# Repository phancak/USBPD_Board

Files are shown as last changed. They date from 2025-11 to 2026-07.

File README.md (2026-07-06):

# ⚡ Modular Power Distribution & USB-PD System

<div align="center">
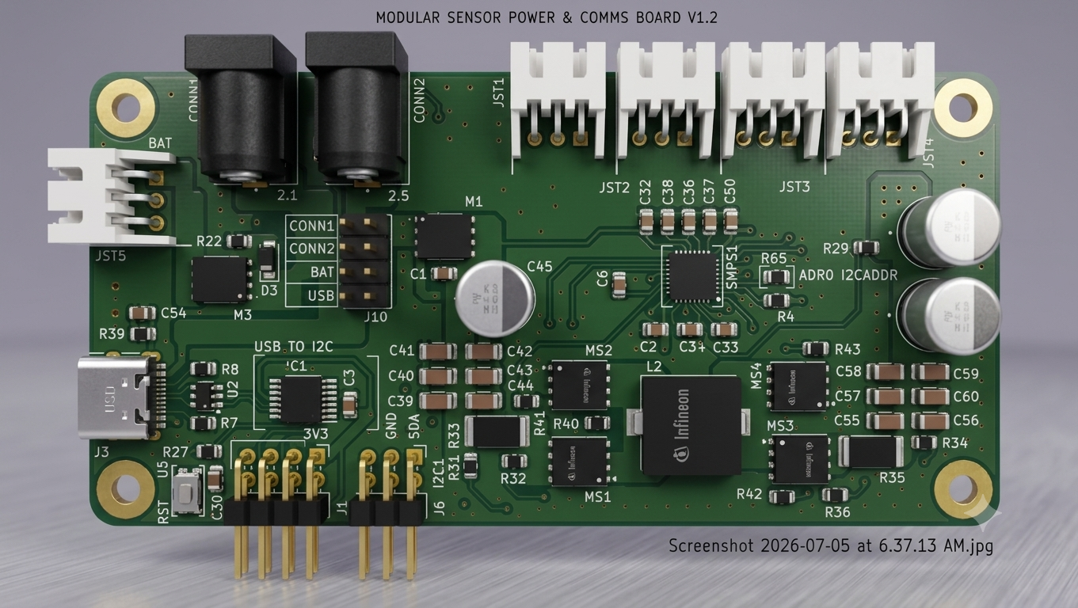
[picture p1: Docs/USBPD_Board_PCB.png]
USBPD PCB 3D Render
  
  <br>
  <em>4-layer PCB diagram.</em>
</div>

### Intelligent Multi-Source Power Management for Mixed-Signal Platforms

## 📑 Quick Access
* [**📂 View Project Schematics (PDF)**](./Schematics/USBPD_Board_Schematics.pdf)

## 📖 Overview
This project is a high-efficiency, multi-input **Power Distribution Board** designed to provide stable, low-noise rails for interchangeable high-performance modules. It serves as the primary power hub for my **24-bit Precision ADC** and **STM32H7S3 System-on-Module** projects.

The system is engineered for maximum field flexibility, allowing a single instrumentation stack to be powered via laboratory bench supplies, USB-C PD sources, or mobile battery packs.

---

## 🛠 Technical Architecture

### 1. Power Entry & Negotiation
The board features a triple-redundant input strategy to support diverse operating environments:
* **USB Power Delivery:** Utilizes an **MCP2221A-I/ST** USB-to-I2C bridge to communicate with PD controllers and negotiate specific voltage profiles.
* **DC Input:** A standard barrel jack for **12V DC** wall converters, ideal for stationary bench-top development.
* **Battery Port:** A dedicated high-current connector for **Lithium-Ion/Polymer battery packs**, enabling untethered mobile data acquisition.

### 2. Digitally Enhanced Conversion
At the core is the **MCP19061-E/RTB**, a Digitally Enhanced Power Analog (DEPA) controller. 
* **Integrated MCU Control:** Combines the performance of an analog peak current mode controller with the flexibility of a microcontroller.
* **Dynamic Regulation:** Enables real-time telemetry and adjustment of output levels to match the requirements of the downstream load.
* **Protection Circuitry:** Hardware-level Under-Voltage Lockout (UVLO), Over-Voltage Protection (OVP), and thermal shutdown.

### 3. Distribution & Filtering
* **4-Way Power Bus:** Features four precision power connectors to distribute clean rails to a stack of interchangeable boards.
* **Noise Mitigation:** Designed with localized LC filtering and optimized PCB return paths to ensure switching noise from the DC-DC stage does not compromise the 120dB SNR performance of connected ADC modules.

---

## 📐 Hardware Specifications

| Feature | Component / Specification |
| :--- | :--- |
| **Main Controller** | Microchip MCP19061 (Integrated MCU + PWM) |
| **USB Interface** | MCP2221A-I/ST (USB-to-I2C/UART Bridge) |
| **Input Range** | Negotiated USB-PD / 12V DC / Battery |
| **Topology** | Synchronous Buck-Boost Converter |
| **Output Ports** | 4x Interconnect Headers |

---

## 🏗 System Integration Philosophy
This board was developed to solve the "Power Bottleneck" in modular hardware design. By decoupling the power stage from the logic and sensing stages, the system achieves:

1.  **High Modularity:** The "Interchangeable Device" architecture allows for swapping analog front-ends or digital processing units without redesigning the power delivery network.
2.  **Field Readiness:** The seamless transition to battery power makes the entire instrumentation stack viable for real-world environmental and oceanographic data collection.
3.  **Stability:** Centralized regulation reduces ground loops and phase coherency issues common in multi-board "nest" wiring.

---

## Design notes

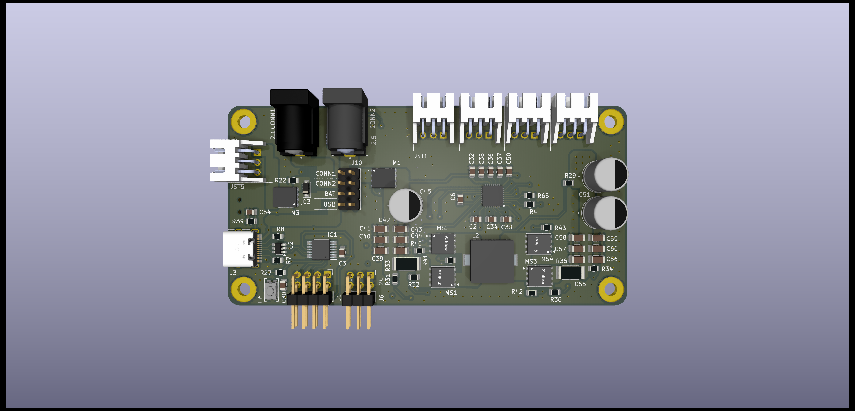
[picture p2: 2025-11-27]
USBPD_Board.png

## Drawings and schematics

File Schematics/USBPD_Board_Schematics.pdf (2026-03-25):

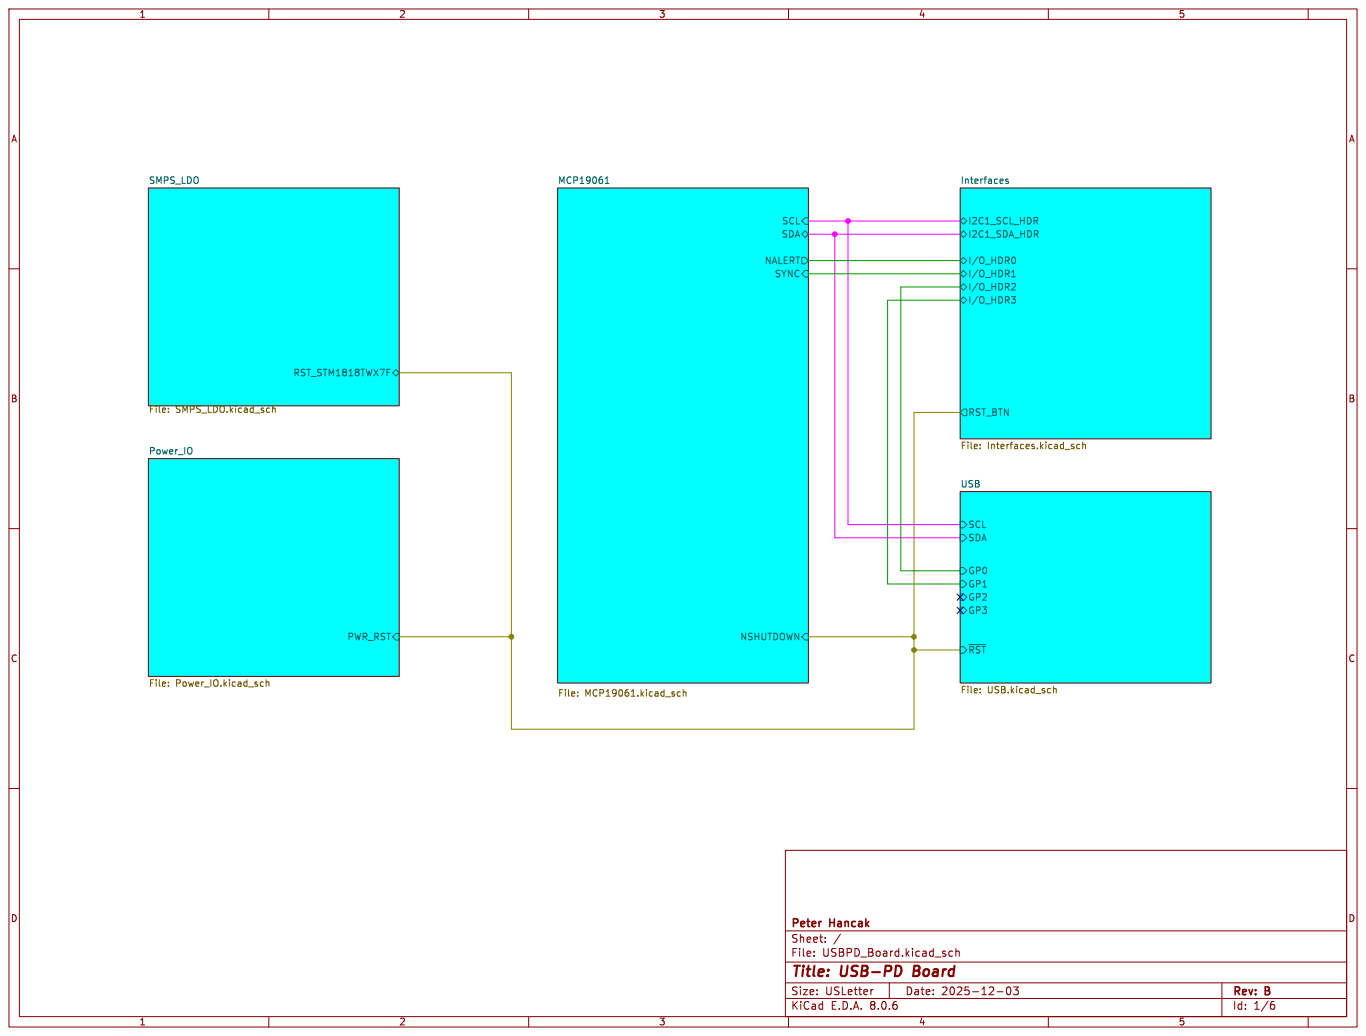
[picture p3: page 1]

Id: 1/6 Title: USB-PD Board

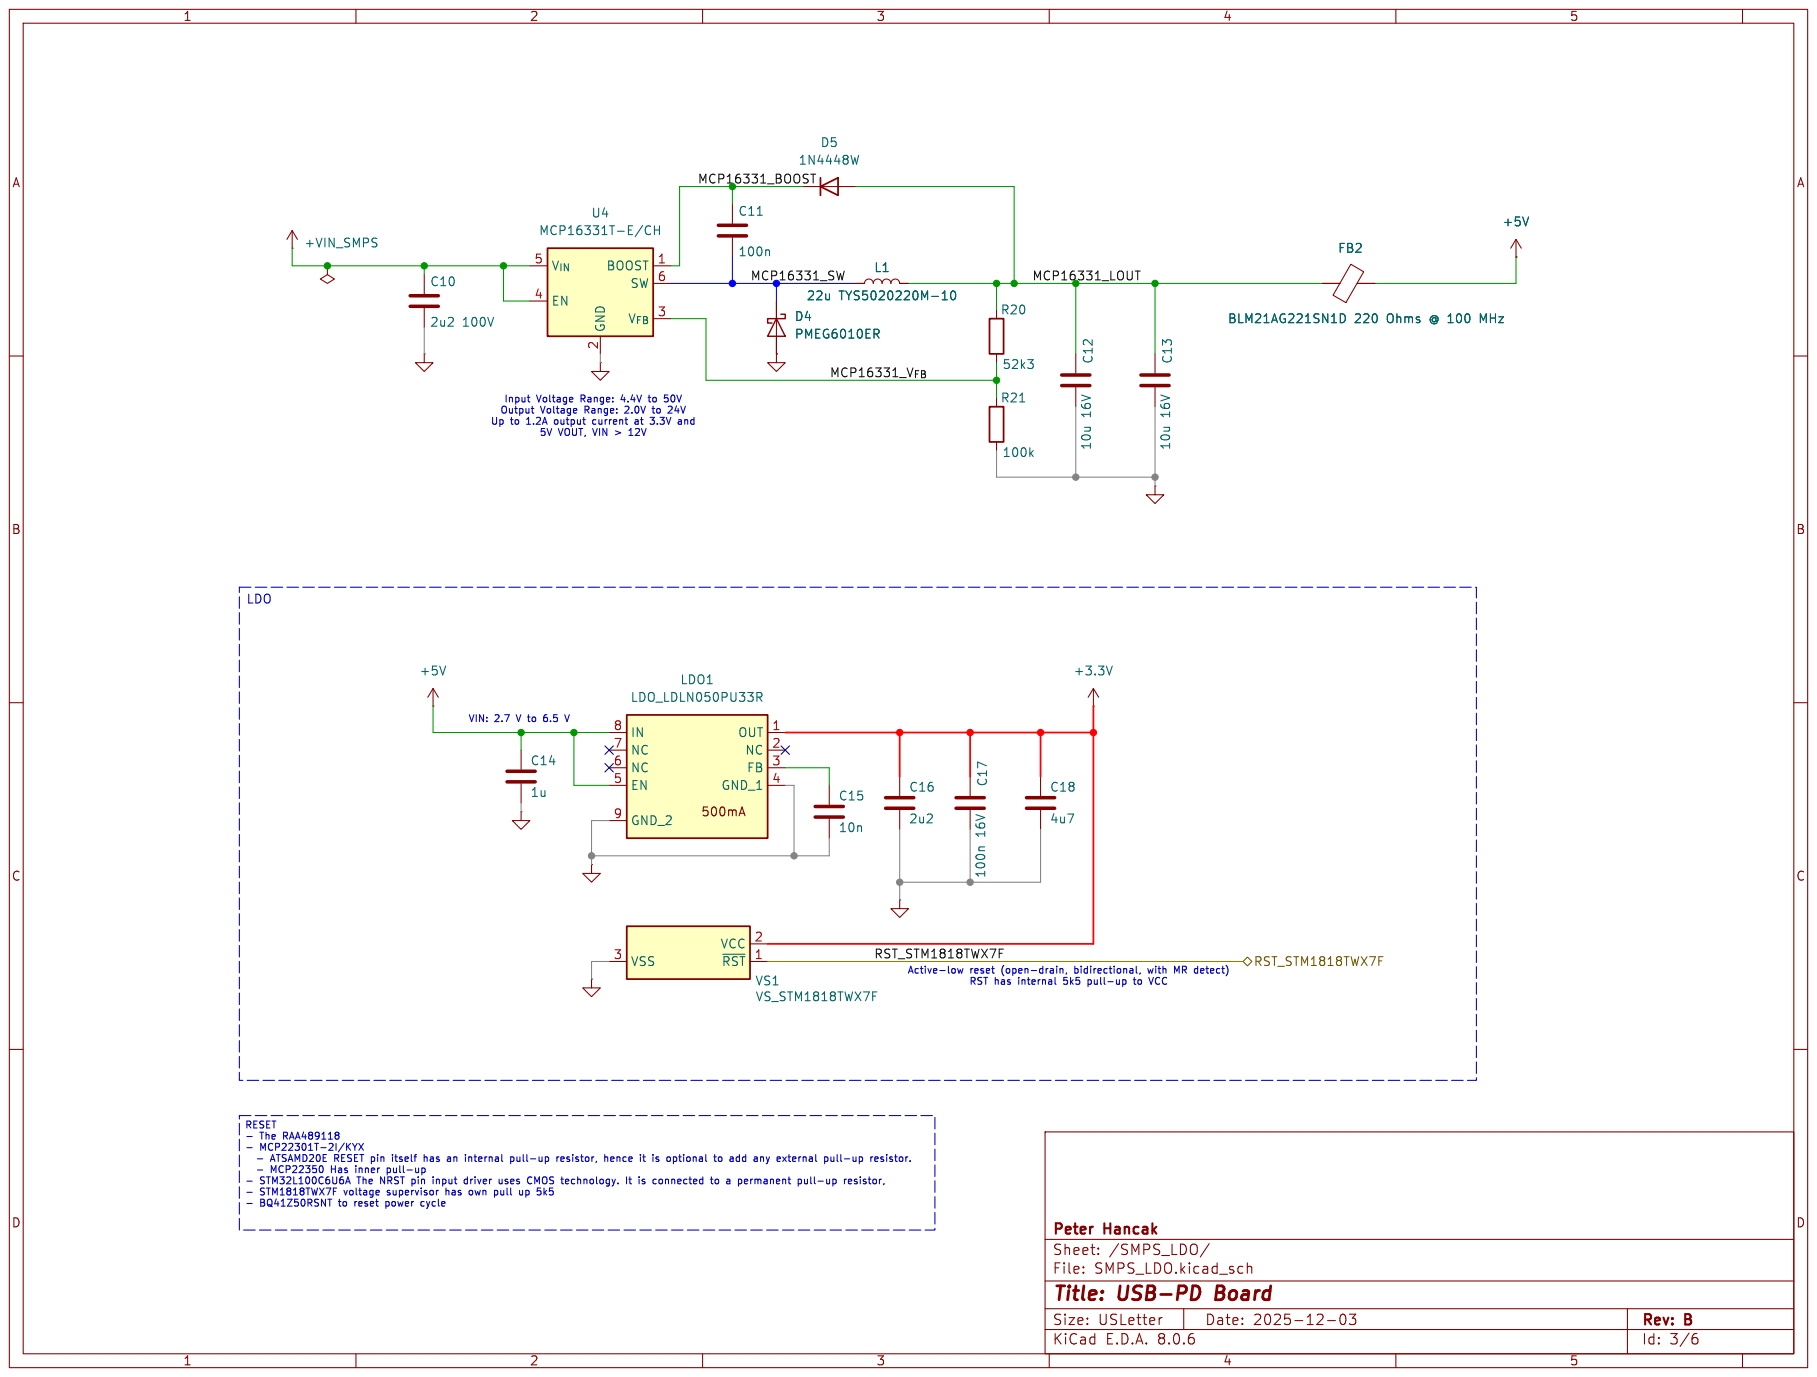
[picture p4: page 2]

2 V_{FB}3 EN 4 V_{IN} 5 SW 6 U4 MCP16331T-E/CH

- BQ41Z50RSNT to reset power cycle

Id: 3/6 Title: USB-PD Board

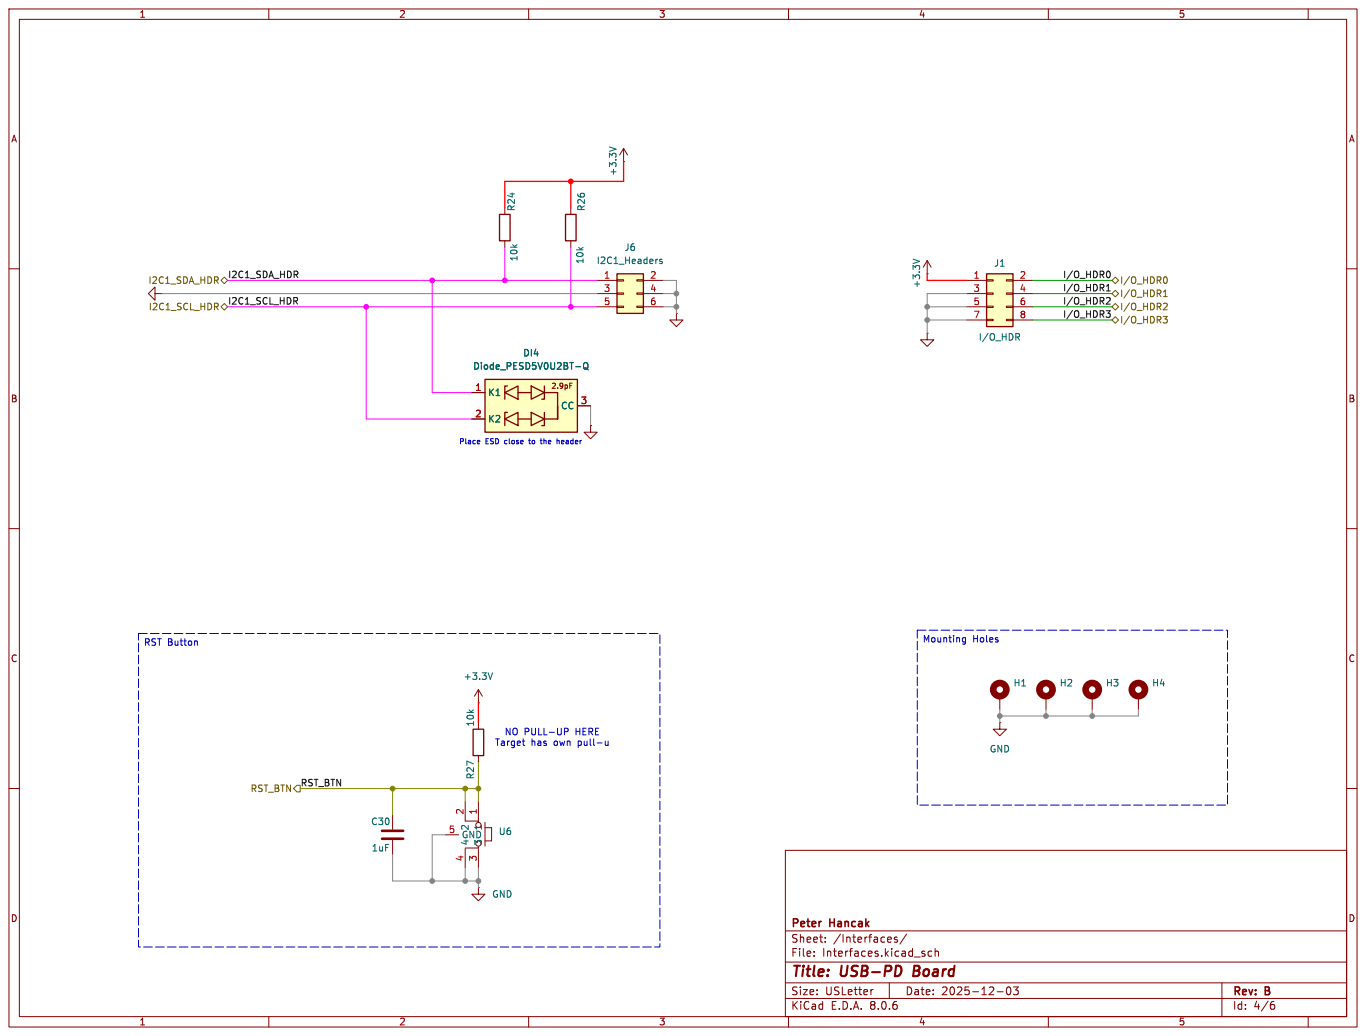
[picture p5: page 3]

Id: 4/6 Title: USB-PD Board

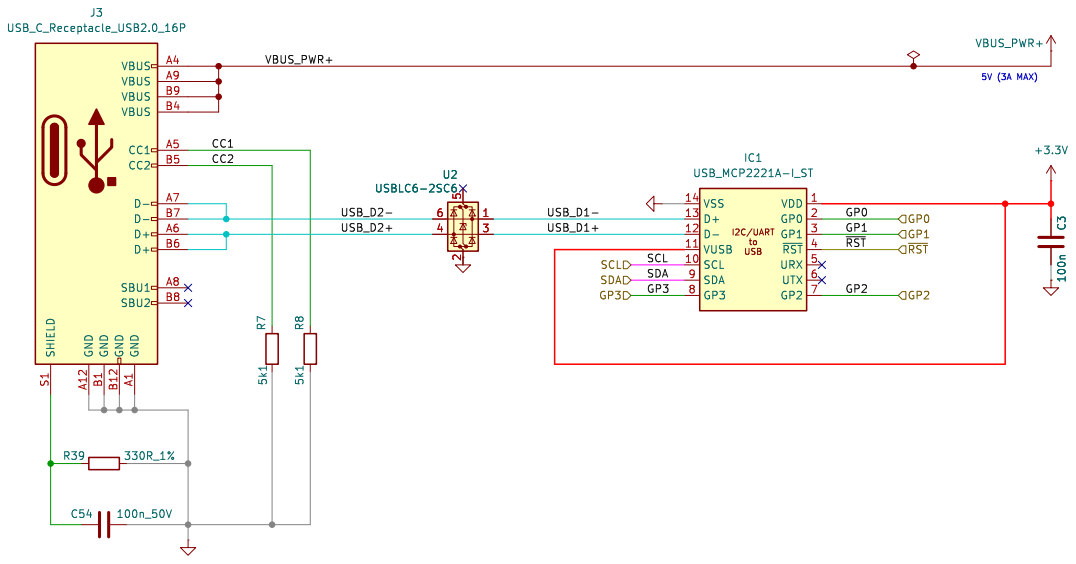
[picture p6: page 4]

Id: 6/6 Title: USB-PD Board

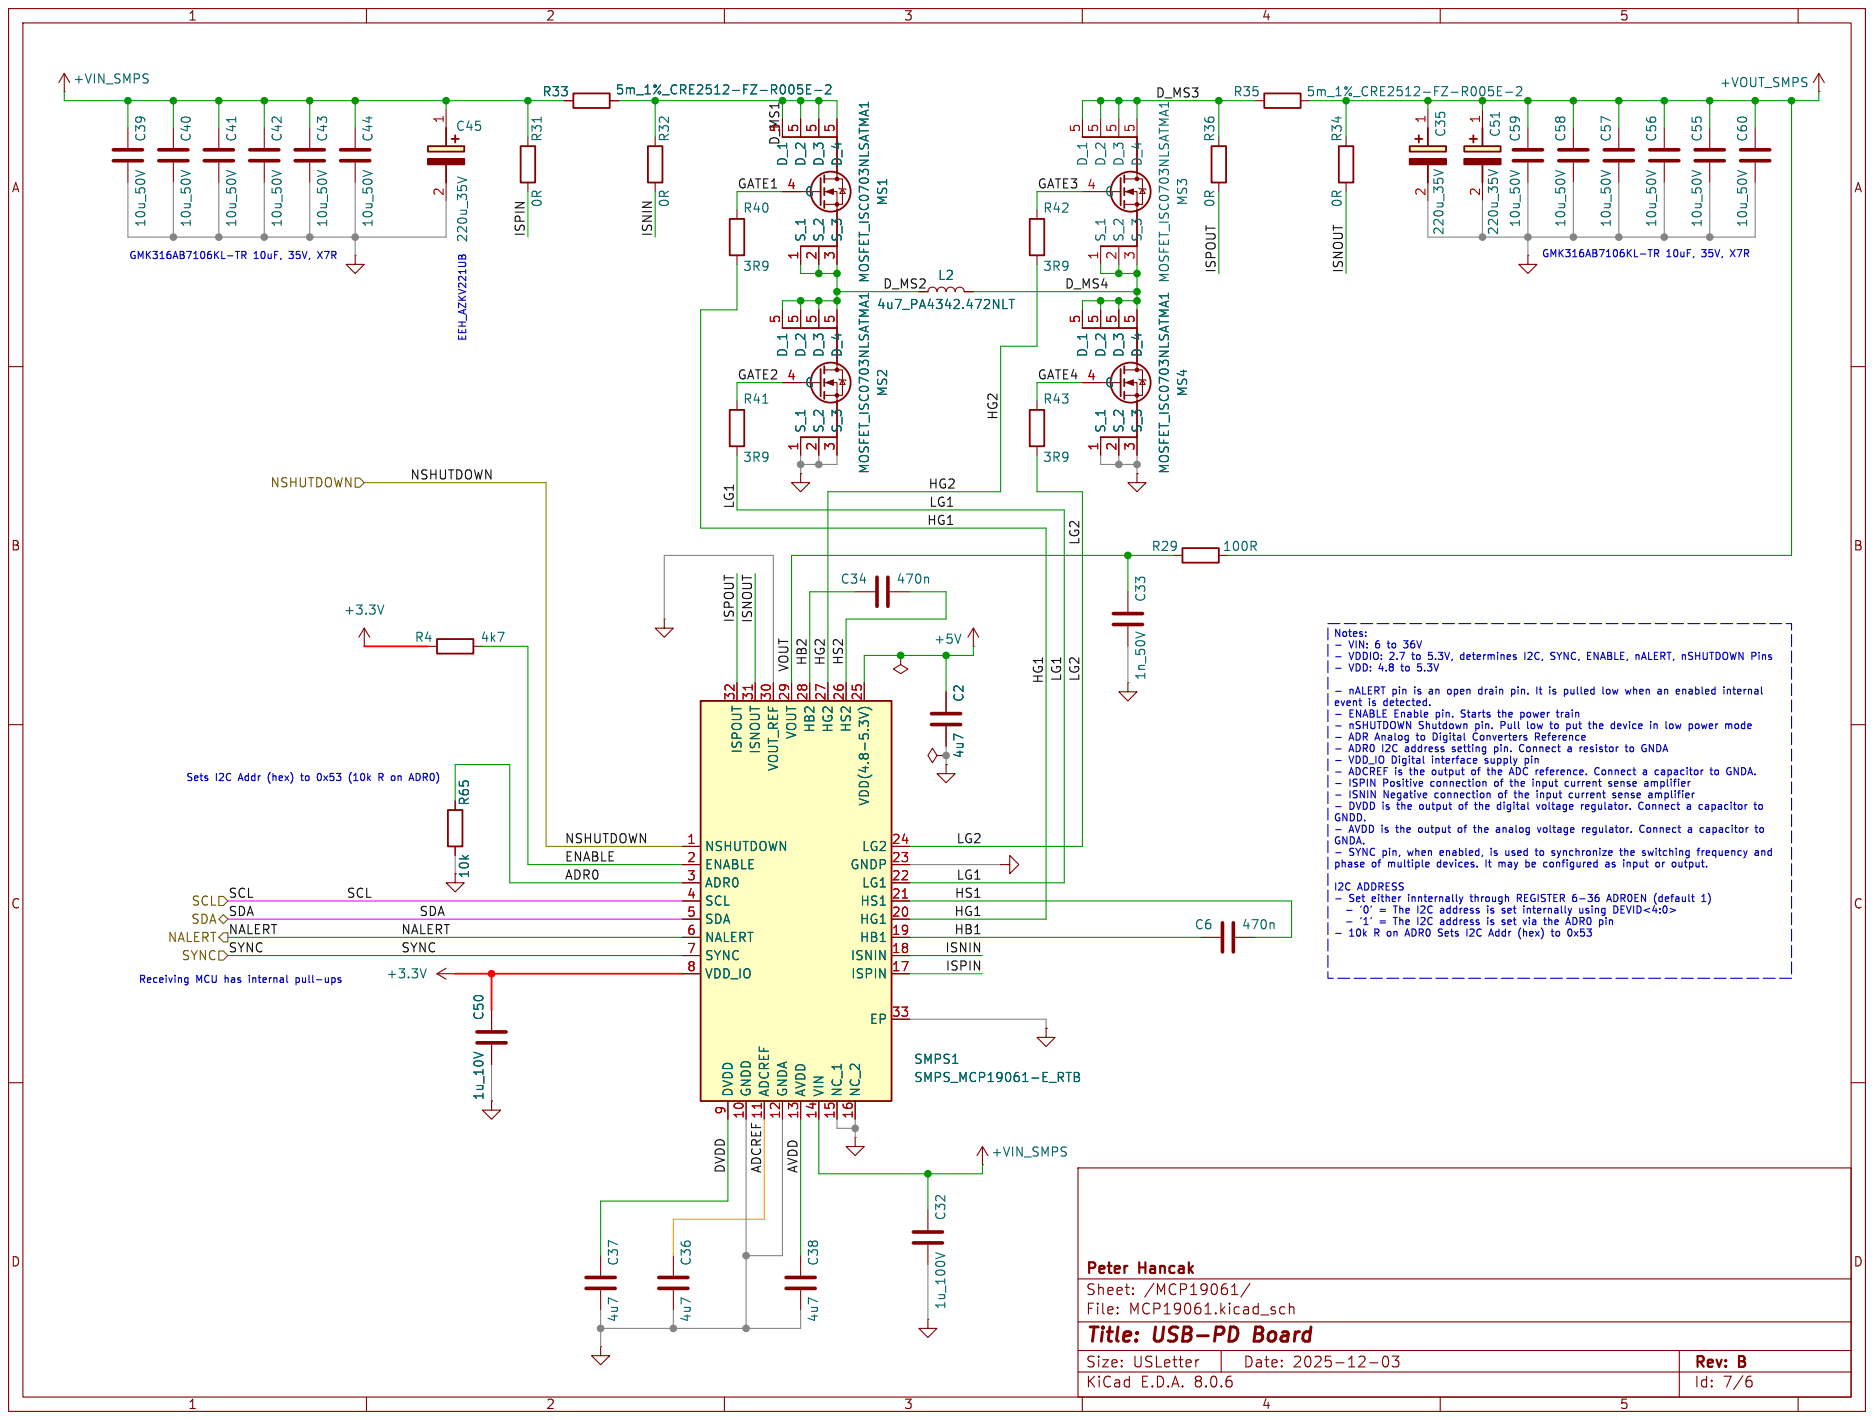
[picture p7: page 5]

- 10k R on ADR0 Sets I2C Addr (hex) to 0x53 C2 4u7

- nALERT pin is an open drain pin. It is pulled low when an enabled internal event is detected. - ENABLE Enable pin. Starts the power train

- nSHUTDOWN Shutdown pin. Pull low to put the device in low power mode

I2C ADDRESS
- '1' = The I2C address is set via the ADR0 pin

Id: 7/6 Title: USB-PD Board

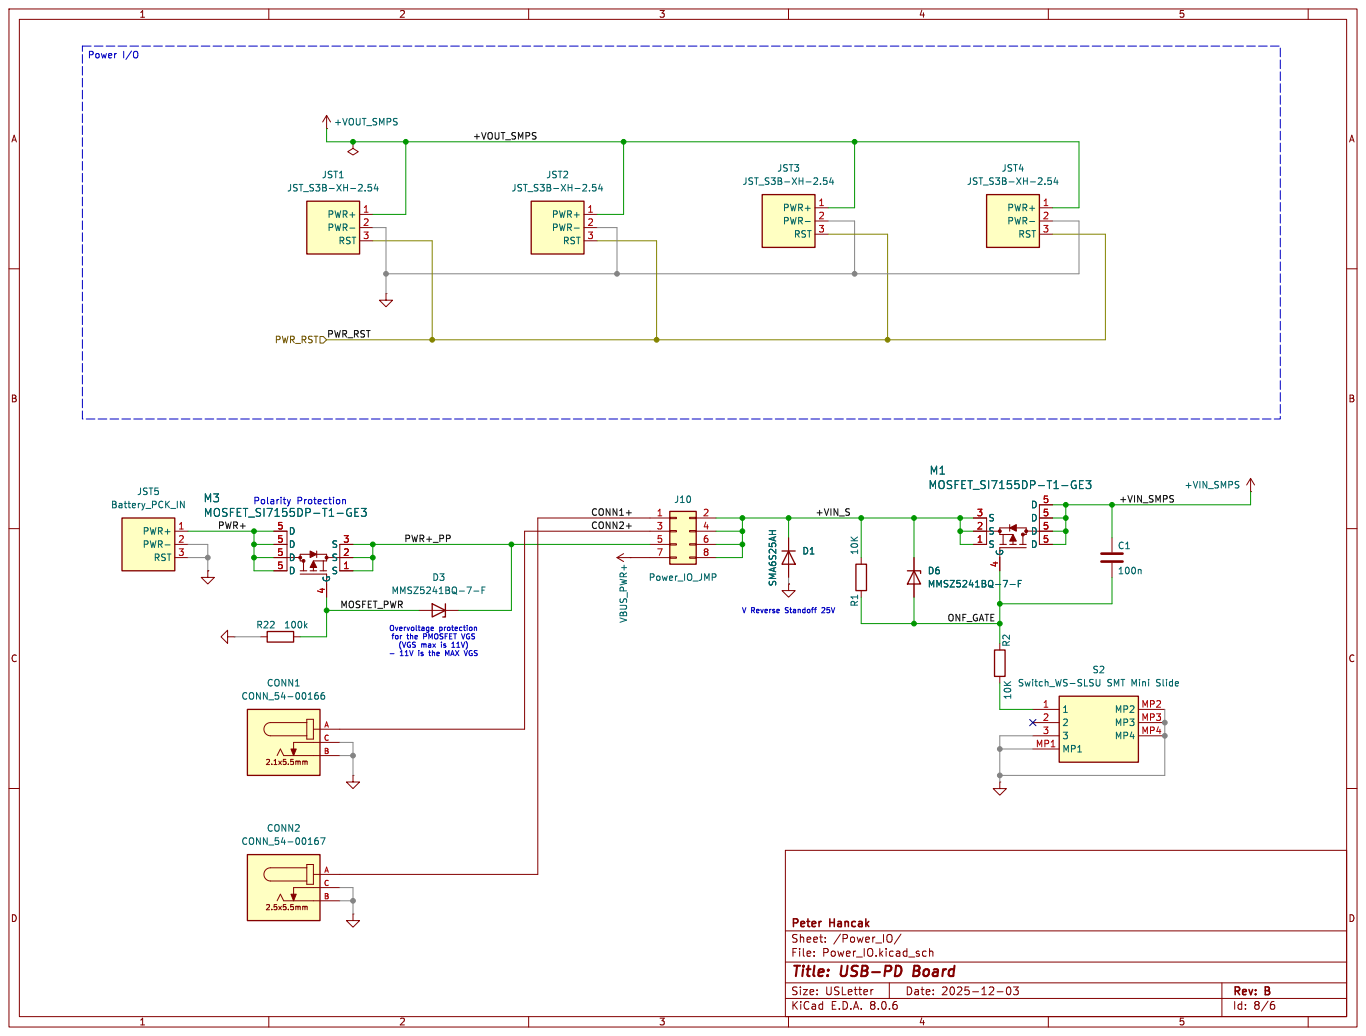
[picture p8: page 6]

for the PMOSFET VGS
(VGS max is 11V)
- 11V is the MAX VGS

Id: 8/6 Title: USB-PD Board

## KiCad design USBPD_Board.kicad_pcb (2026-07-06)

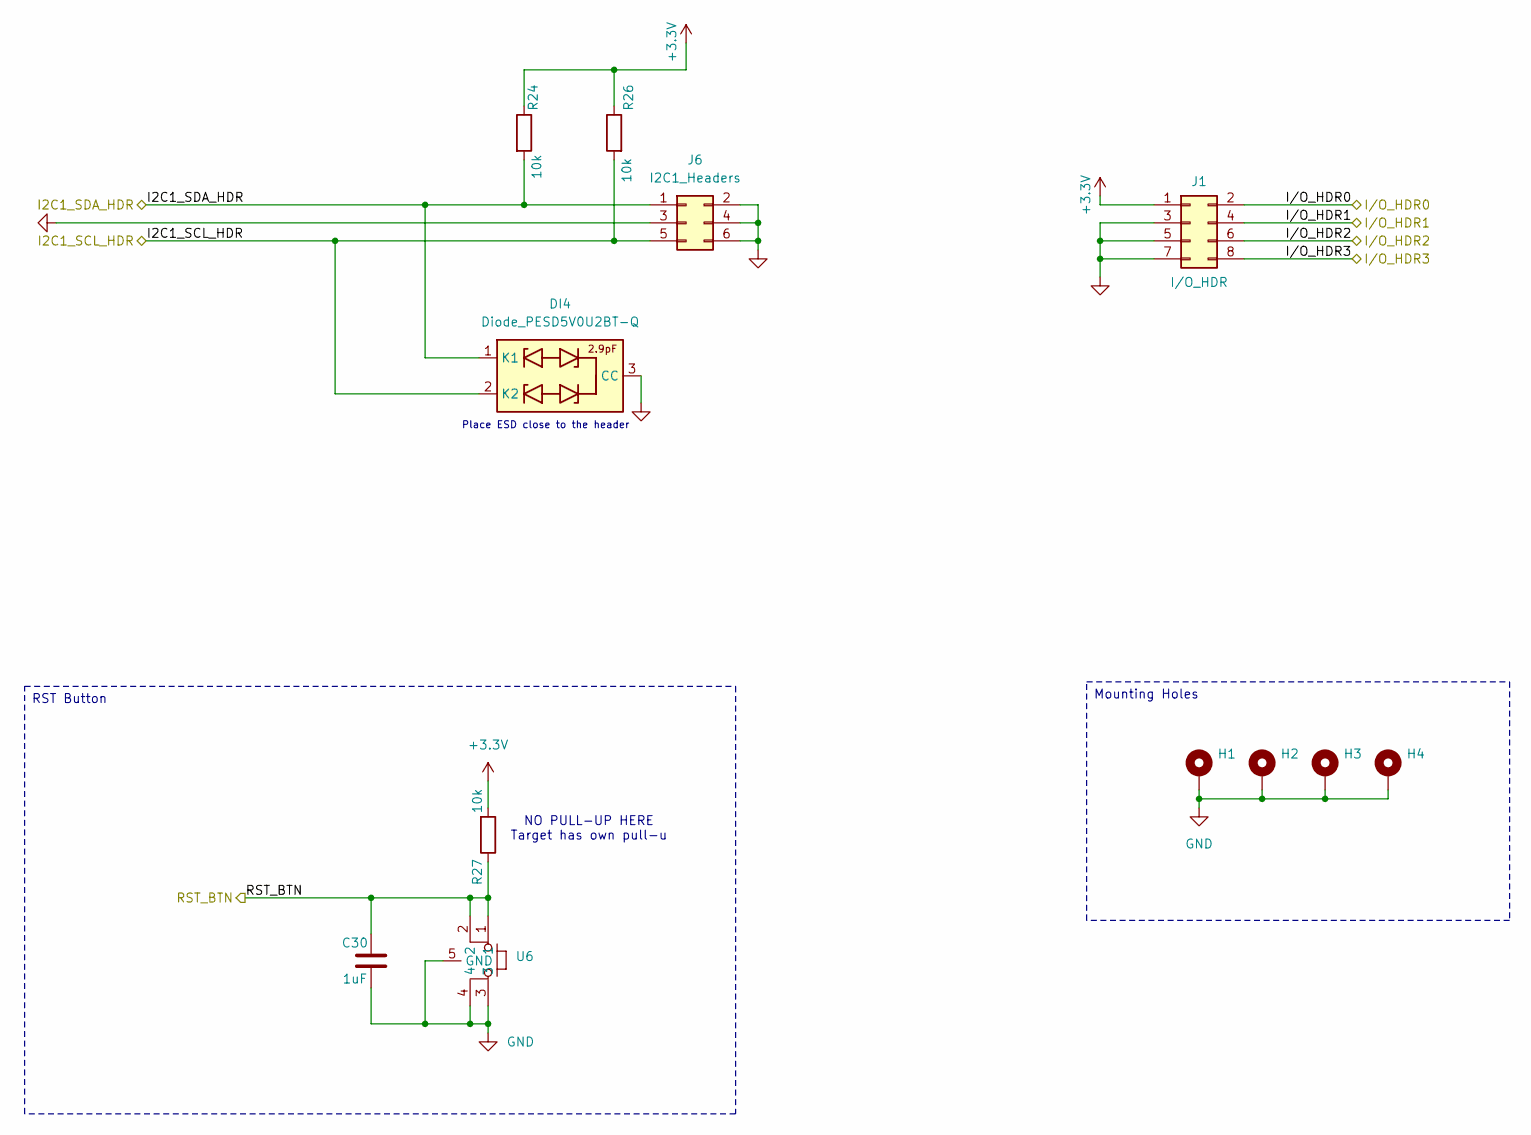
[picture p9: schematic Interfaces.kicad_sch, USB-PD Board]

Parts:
C30: 1uF; C_0805_2012Metric
DI4: Diode_PESD5V0U2BT-Q; SOT-23; Manufacturer_Part_Number BZX84C6V2-7-F; Mouser Part Number 621-BZX84C6V2-F
H1, H2, H3, H4: MountingHole_Pad; MountingHole_3.2mm_M3_Pad
J1: I/O_HDR; PinHeader_2x04_P2.54mm_Horizontal
J6: I2C1_Headers; PinHeader_2x03_P2.54mm_Horizontal
R24, R26, R27: 10k; R_0805_2012Metric
U6: Button_KMR231GLFS

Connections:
+3.3V: J1.1, R24.1, R26.1, R27.2; also elsewhere on the board
/Interfaces/I2C1_SCL_HDR: DI4.2 (K2), J6.5, R26.2; also elsewhere on the board
/Interfaces/I2C1_SDA_HDR: DI4.1 (K1), J6.1, R24.2; also elsewhere on the board
/Interfaces/I/O_HDR0: J1.2; also elsewhere on the board
/Interfaces/I/O_HDR1: J1.4; also elsewhere on the board
/Interfaces/I/O_HDR2: J1.6; also elsewhere on the board
/Interfaces/I/O_HDR3: J1.8; also elsewhere on the board
/Interfaces/RST_BTN: C30.2, R27.1, U6.1, U6.2; also elsewhere on the board
GND: C30.1, DI4.3 (CC), H1.1, H2.1, H3.1, H4.1, J1.3, J1.5, J1.7, J6.2, J6.3, J6.4, J6.6, U6.3, U6.4, U6.5 (GND); also elsewhere on the board

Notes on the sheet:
Place ESD close to the header
NO PULL-UP HERE Target has own pull-u
Mounting Holes
RST Button

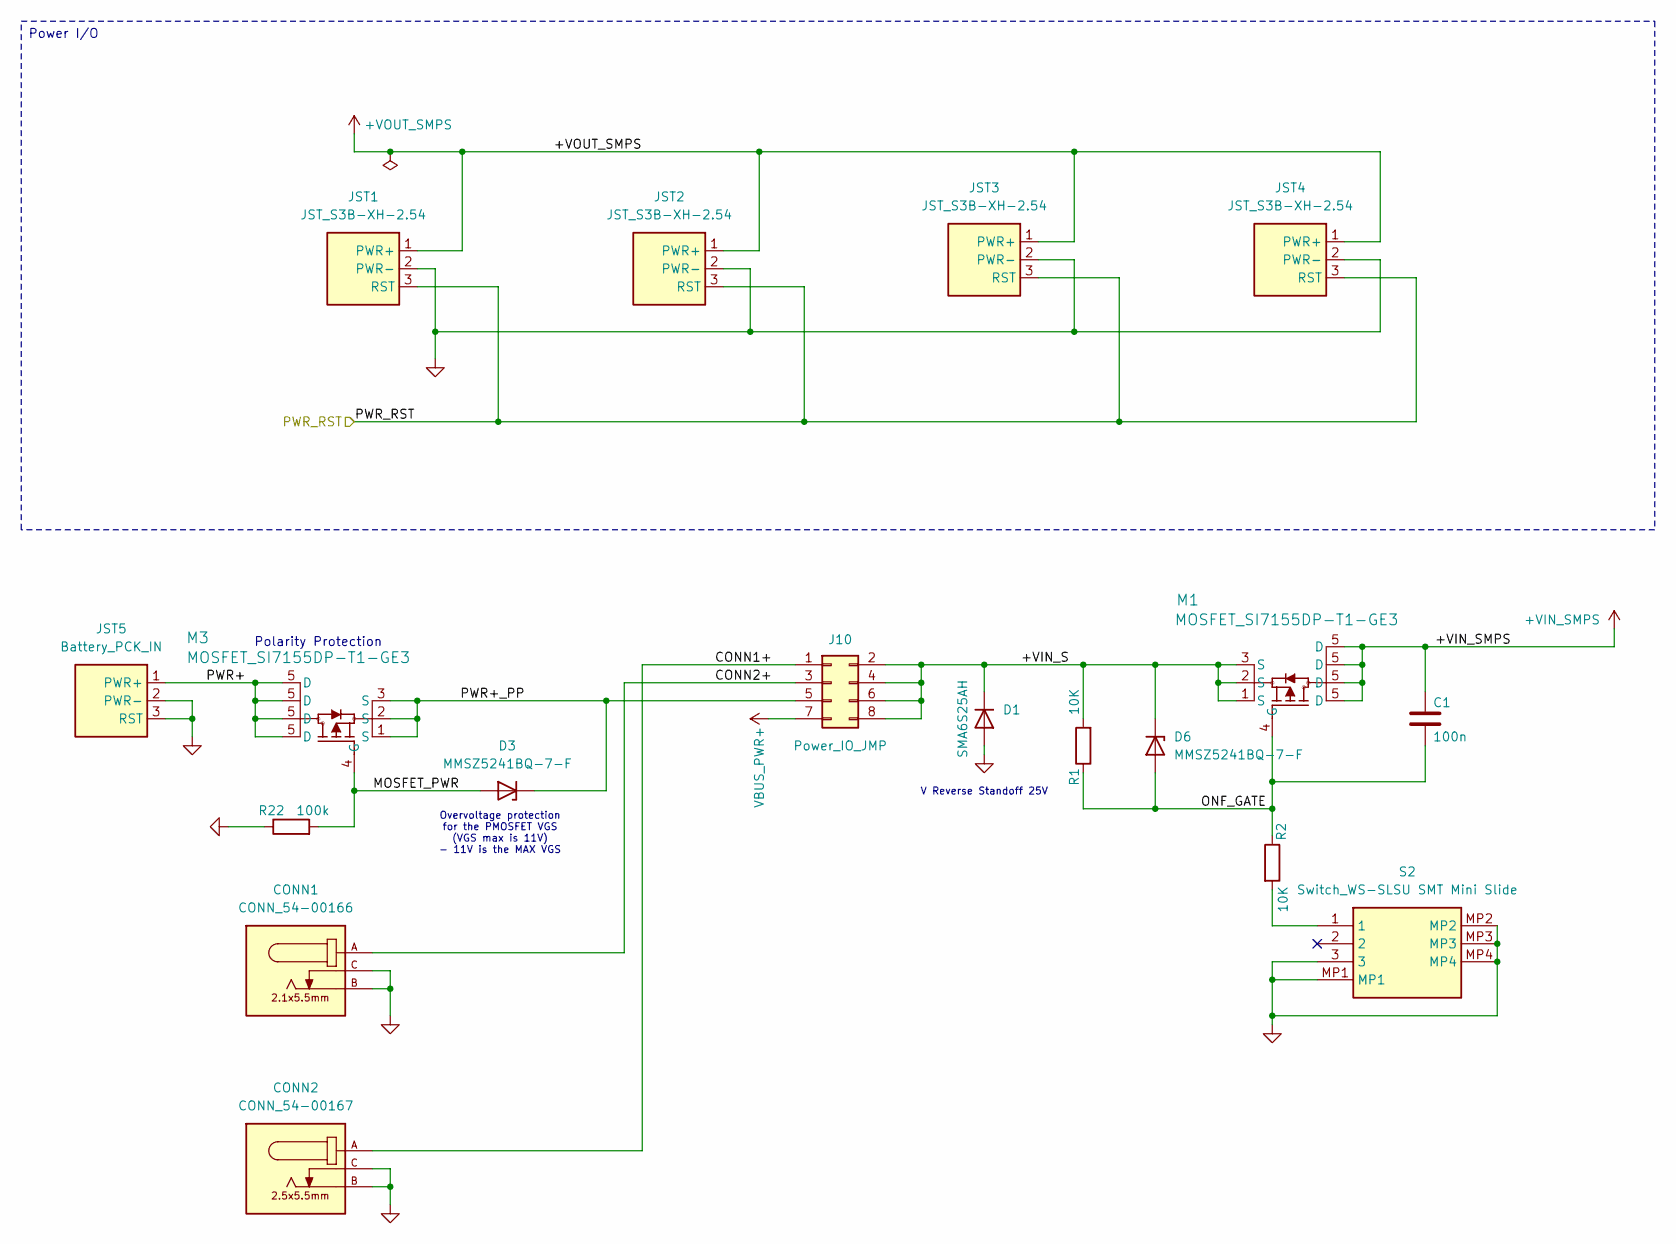
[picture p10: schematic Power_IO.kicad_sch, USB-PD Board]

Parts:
C1: 100n; C_0805_2012Metric
CONN1: CONN_54-00166; PARTREV A
CONN2: CONN_54-00167; PARTREV A
D1: SMA6S25AH; D_SOD-123
D3, D6: MMSZ5241BQ-7-F; D_SOD-123
J10: Power_IO_JMP; PinHeader_2x04_P2.54mm_Vertical
JST1, JST2, JST3, JST4: JST_S3B-XH-2.54; JST_S3B-XH-SHDRRA3W64P0X250_1X3_990X1150X610P; Mouser Part Number 306-S3BXHA1LFSN
JST5: Battery_PCK_IN; JST_S3B-XH-SHDRRA3W64P0X250_1X3_990X1150X610P; Mouser Part Number 306-S3BXHA1LFSN
M1, M3: MOSFET_SI7155DP-T1-GE3; MOSFET_SI7155DPT1GE3
R1, R2: 10K; R_0805_2012Metric
R22: 100k; R_0805_2012Metric
S2: Switch_WS-SLSU SMT Mini Slide; Mouser Part Number 710-450404015514

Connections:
+VIN_SMPS: C1.1, M1.5 (D); also elsewhere on the board
+VOUT_SMPS: JST1.1 (PWR+), JST2.1 (PWR+), JST3.1 (PWR+), JST4.1 (PWR+); also elsewhere on the board
/Interfaces/RST_BTN: JST1.3 (RST), JST2.3 (RST), JST3.3 (RST), JST4.3 (RST); also elsewhere on the board
/Power_IO/+VIN_S: D1.1 (K), D6.1 (K), J10.2, J10.4, J10.6, J10.8, M1.1 (S), M1.2 (S), M1.3 (S), R1.2
/Power_IO/CONN1+: CONN2.A, J10.1
/Power_IO/CONN2+: CONN1.A, J10.3
/Power_IO/MOSFET_PWR: D3.2 (A), M3.4 (G), R22.2
/Power_IO/ONF_GATE: C1.2, D6.2 (A), M1.4 (G), R1.1, R2.1
/Power_IO/PWR+: JST5.1 (PWR+), M3.5 (D)
/Power_IO/PWR+_PP: D3.1 (K), J10.5, M3.1 (S), M3.2 (S), M3.3 (S)
GND: CONN1.B, CONN1.C, CONN2.B, CONN2.C, D1.2 (A), JST1.2 (PWR-), JST2.2 (PWR-), JST3.2 (PWR-), JST4.2 (PWR-), JST5.2 (PWR-), JST5.3 (RST), R22.1, S2.3, S2.MP1, S2.MP2, S2.MP3, S2.MP4; also elsewhere on the board
unnamed: R2.2, S2.1
VBUS_PWR+: J10.7; also elsewhere on the board

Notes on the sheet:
Overvoltage protection for the PMOSFET VGS (VGS max is 11V) - 11V is the MAX VGS
V Reverse Standoff 25V
Polarity Protection
Power I/O

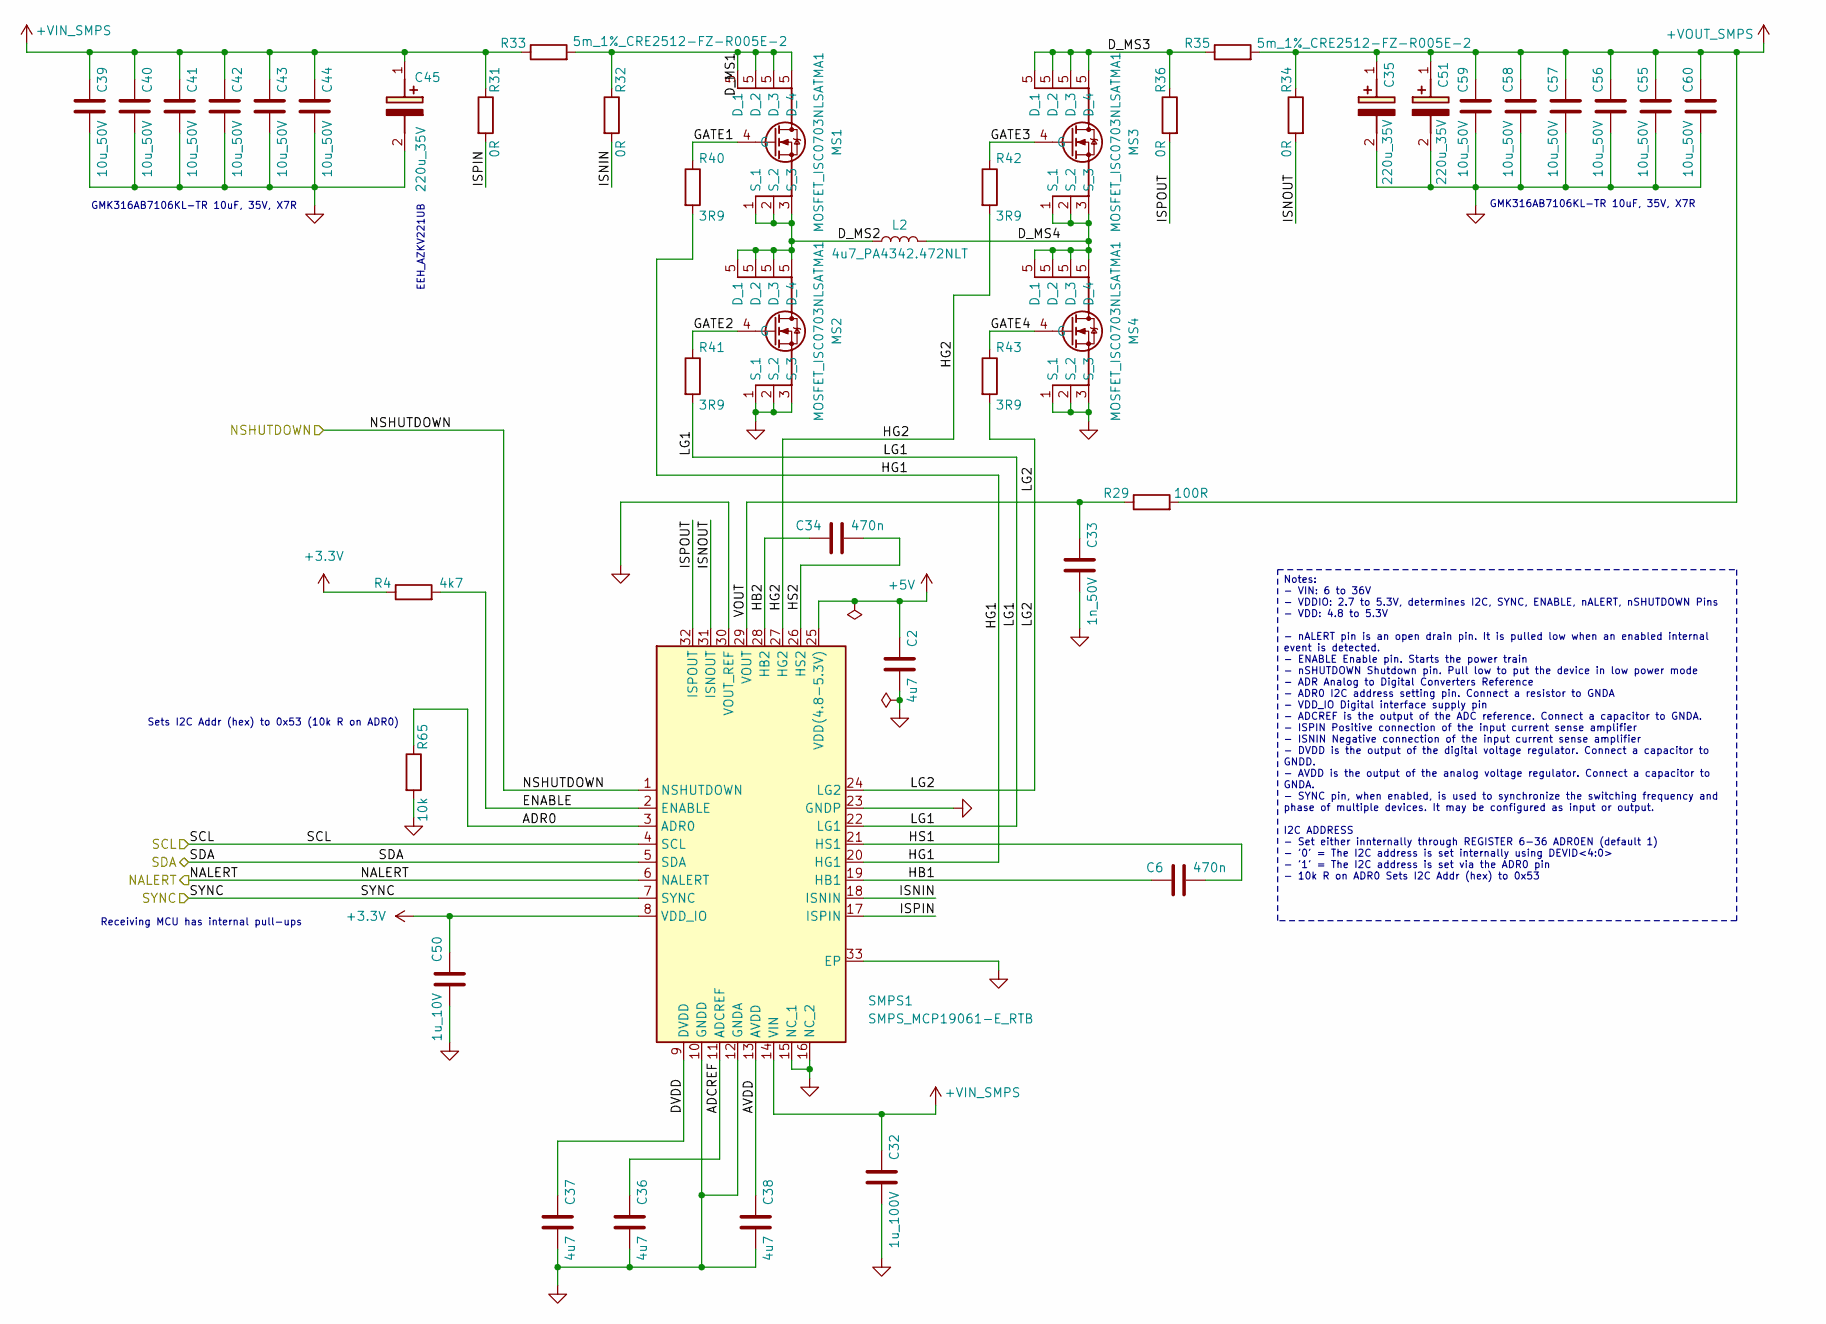
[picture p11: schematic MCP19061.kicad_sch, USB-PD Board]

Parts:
C2, C36, C37, C38: 4u7; C_0805_2012Metric
C6, C34: 470n; C_0805_2012Metric
C32: 1u_100V; C_0805_2012Metric
C33: 1n_50V; C_0805_2012Metric
C35, C45, C51: 220u_35V; C_EEHAZKV221UB_CAPPRD350W60D800H950; Mouser Part Number 80-T530Y337M6ATE6
C39, C40, C41, C42, C43, C44, C55, C56, C57, C58, C59, C60: 10u_50V; C_1206_3216Metric
C50: 1u_10V; C_0805_2012Metric
L2: 4u7_PA4342.472NLT; L_PA4342472NLT
MS1, MS2, MS3, MS4: MOSFET_ISC0703NLSATMA1; IPC100N04S51R2ATMA1; Manufacturer_Part_Number IAUCN08S7N034ATMA1
R4: 4k7; R_0805_2012Metric
R29: 100R; R_0805_2012Metric
R31, R32, R34, R36: 0R; R_0805_2012Metric
R33, R35: 5m_1%_CRE2512-FZ-R005E-2; R_2512_6332Metric
R40, R41, R42, R43: 3R9; R_0805_2012Metric
R65: 10k; R_0805_2012Metric
SMPS1: SMPS_MCP19061-E_RTB; SMPS_MCP19061_QFN50P500X500X100-33N-D; Manufacturer_Part_Number MCP19061-E/RTB

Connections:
+3.3V: C50.1, R4.1, SMPS1.8 (VDD_IO); also elsewhere on the board
+5V: C2.1, SMPS1.25 (VDD(4.8-5.3V)); also elsewhere on the board
+VIN_SMPS: C32.1, C39.1, C40.1, C41.1, C42.1, C43.1, C44.1, C45.1 (+), R31.1, R33.1, SMPS1.14 (VIN); also elsewhere on the board
+VOUT_SMPS: C35.1 (+), C51.1 (+), C55.1, C56.1, C57.1, C58.1, C59.1, C60.1, R29.2, R34.1, R35.2; also elsewhere on the board
/Interfaces/I2C1_SCL_HDR: SMPS1.4 (SCL); also elsewhere on the board
/Interfaces/I2C1_SDA_HDR: SMPS1.5 (SDA); also elsewhere on the board
/Interfaces/I/O_HDR0: SMPS1.6 (NALERT); also elsewhere on the board
/Interfaces/I/O_HDR1: SMPS1.7 (SYNC); also elsewhere on the board
/Interfaces/RST_BTN: SMPS1.1 (NSHUTDOWN); also elsewhere on the board
/MCP19061/ADCREF: C36.1, SMPS1.11 (ADCREF)
/MCP19061/ADR0: R65.1, SMPS1.3 (ADR0)
/MCP19061/AVDD: C38.1, SMPS1.13 (AVDD)
/MCP19061/DVDD: C37.1, SMPS1.9 (DVDD)
/MCP19061/D_MS1: MS1.5 (D_1), R32.1, R33.2
/MCP19061/D_MS2: L2.1, MS1.1 (S_1), MS1.2 (S_2), MS1.3 (S_3), MS2.5 (D_1)
/MCP19061/D_MS3: MS3.5 (D_1), R35.1, R36.1
/MCP19061/D_MS4: L2.2, MS3.1 (S_1), MS3.2 (S_2), MS3.3 (S_3), MS4.5 (D_1)
/MCP19061/ENABLE: R4.2, SMPS1.2 (ENABLE)
/MCP19061/GATE1: MS1.4 (G), R40.1
/MCP19061/GATE2: MS2.4 (G), R41.1
/MCP19061/GATE3: MS3.4 (G), R42.1
/MCP19061/GATE4: MS4.4 (G), R43.1
/MCP19061/HB1: C6.1, SMPS1.19 (HB1)
/MCP19061/HB2: C34.1, SMPS1.28 (HB2)
/MCP19061/HG1: R40.2, SMPS1.20 (HG1)
/MCP19061/HG2: R42.2, SMPS1.27 (HG2)
/MCP19061/HS1: C6.2, SMPS1.21 (HS1)
/MCP19061/HS2: C34.2, SMPS1.26 (HS2)
/MCP19061/ISNIN: R32.2, SMPS1.18 (ISNIN)
/MCP19061/ISNOUT: R34.2, SMPS1.31 (ISNOUT)
/MCP19061/ISPIN: R31.2, SMPS1.17 (ISPIN)
/MCP19061/ISPOUT: R36.2, SMPS1.32 (ISPOUT)
/MCP19061/LG1: R41.2, SMPS1.22 (LG1)
/MCP19061/LG2: R43.2, SMPS1.24 (LG2)
/MCP19061/VOUT: C33.1, R29.1, SMPS1.29 (VOUT)
GND: C2.2, C32.2, C33.2, C35.2 (-), C36.2, C37.2, C38.2, C39.2, C40.2, C41.2, C42.2, C43.2, C44.2, C45.2 (-), C50.2, C51.2 (-), C55.2, C56.2, C57.2, C58.2, C59.2, C60.2, MS2.1 (S_1), MS2.2 (S_2), MS2.3 (S_3), MS4.1 (S_1), MS4.2 (S_2), MS4.3 (S_3), R65.2, SMPS1.10 (GNDD), SMPS1.12 (GNDA), SMPS1.15 (NC_1), SMPS1.16 (NC_2), SMPS1.23 (GNDP), SMPS1.30 (VOUT_REF), SMPS1.33 (EP); also elsewhere on the board

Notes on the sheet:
GMK316AB7106KL-TR 10uF, 35V, X7R
Sets I2C Addr (hex) to 0x53 (10k R on ADR0)
EEH_AZKV221UB
Receiving MCU has internal pull-ups
Notes: - VIN: 6 to 36V - VDDIO: 2.7 to 5.3V, determines I2C, SYNC, ENABLE, nALERT, nSHUTDOWN Pins - VDD: 4.8 to 5.3V - nALERT pin is an open drain pin. It is pulled low when an enabled internal event is detected. - ENABLE Enable pin. Starts the power train - nSHUTDOWN Shutdown pin. Pull low to put 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

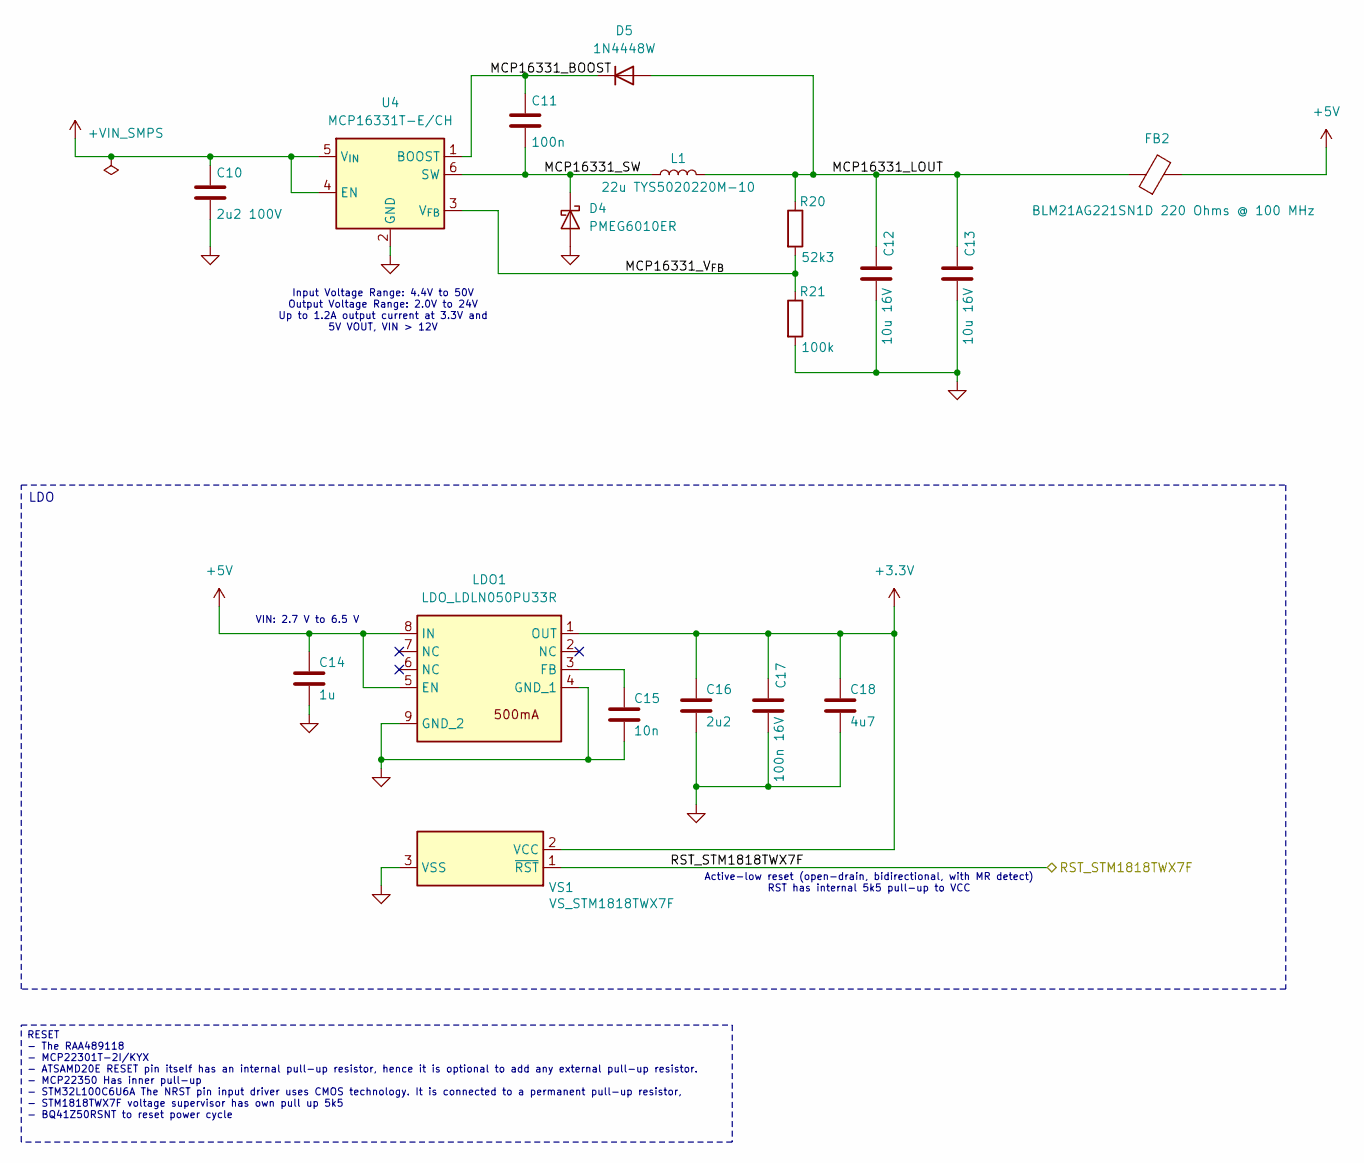
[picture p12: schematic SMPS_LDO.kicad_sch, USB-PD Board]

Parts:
C10: 2u2 100V; C_0805_2012Metric
C11: 100n; C_0805_2012Metric
C12, C13: 10u 16V; C_0805_2012Metric
C14: 1u; C_0805_2012Metric
C15: 10n; C_0805_2012Metric
C16: 2u2; C_0805_2012Metric
C17: 100n 16V; C_0805_2012Metric
C18: 4u7; C_0805_2012Metric
D4: PMEG6010ER; Nexperia_CFP3_SOD-123W
D5: 1N4448W; D_SOD-123
FB2: BLM21AG221SN1D 220 Ohms @ 100 MHz; C_0805_2012Metric
L1: 22u TYS5020220M-10; L_Changjiang_FNR5020S
LDO1: LDO_LDLN050PU33R; DFN-8-1EP_3x3mm_P0.65mm_EP1.7x2.05mm; Manufacturer_Part_Number LD39200DPUR; Mouser Part Number 511-LD39200DPUR
R20: 52k3; R_1206_3216Metric
R21: 100k; R_1206_3216Metric
U4: MCP16331T-E/CH; SOT-23-6
VS1: VS_STM1818TWX7F; SOT-23-3_SOT103P237X112-3N; Mouser Part Number 511-STM1813LWX7F

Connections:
+3.3V: C16.1, C17.1, C18.1, LDO1.1 (OUT), VS1.2 (VCC); also elsewhere on the board
+5V: C14.1, FB2.2, LDO1.5 (EN), LDO1.8 (IN); also elsewhere on the board
+VIN_SMPS: C10.1, U4.4 (EN), U4.5 (V_{IN}); also elsewhere on the board
/Interfaces/RST_BTN: VS1.1 (~RST); also elsewhere on the board
/SMPS_LDO/MCP16331_BOOST: C11.1, D5.1 (K), U4.1 (BOOST)
/SMPS_LDO/MCP16331_LOUT: C12.1, C13.1, D5.2 (A), FB2.1, L1.2, R20.1
/SMPS_LDO/MCP16331_SW: C11.2, D4.1 (K), L1.1, U4.6 (SW)
/SMPS_LDO/MCP16331_V_{FB}: R20.2, R21.1, U4.3 (V_{FB})
GND: C10.2, C12.2, C13.2, C14.2, C15.2, C16.2, C17.2, C18.2, D4.2 (A), LDO1.4 (GND_1), LDO1.9 (GND_2), R21.2, U4.2 (GND), VS1.3 (VSS); also elsewhere on the board
unnamed: C15.1, LDO1.3 (FB)

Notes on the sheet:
Active-low reset (open-drain, bidirectional, with MR detect) RST has internal 5k5 pull-up to VCC
Input Voltage Range: 4.4V to 50V Output Voltage Range: 2.0V to 24V Up to 1.2A output current at 3.3V and 5V VOUT, VIN > 12V
VIN: 2.7 V to 6.5 V
LDO
RESET - The RAA489118 - MCP22301T-2I/KYX - ATSAMD20E RESET pin itself has an internal pull-up resistor, hence it is optional to add any external pull-up resistor. - MCP22350 Has inner pull-up - STM32L100C6U6A The NRST pin input driver uses CMOS technology. It is connected to a permanent pull-up res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

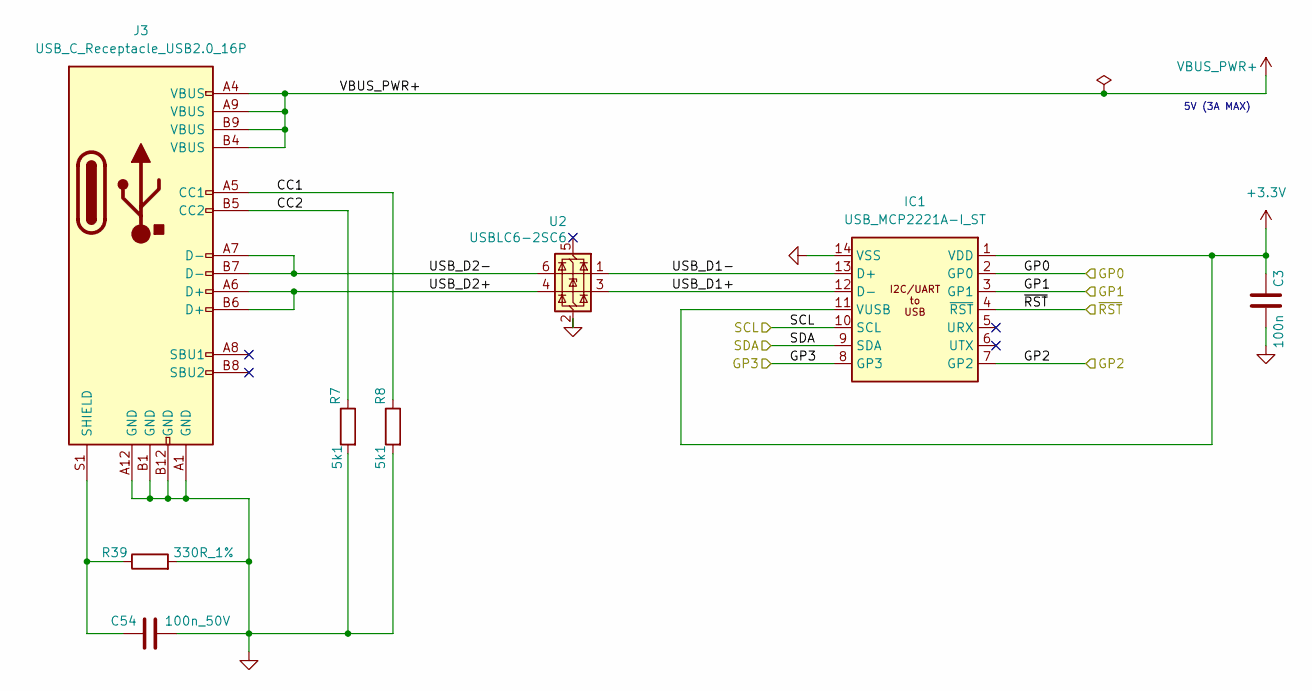
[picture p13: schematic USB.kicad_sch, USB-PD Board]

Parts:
C3: 100n; C_0805_2012Metric
C54: 100n_50V; C_0805_2012Metric
IC1: USB_MCP2221A-I_ST; SOP65P640X120-14N; Mouser Part Number 579-MCP2221A-I/ST
J3: USB_C_Receptacle_USB2.0_16P; USB_C_Receptacle_HRO_TYPE-C-31-M-12
R7, R8: 5k1; R_0805_2012Metric
R39: 330R_1%; R_0805_2012Metric
U2: USBLC6-2SC6; SOT-23-6

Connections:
+3.3V: C3.1, IC1.1 (VDD), IC1.11 (VUSB); also elsewhere on the board
/Interfaces/I2C1_SCL_HDR: IC1.10 (SCL); also elsewhere on the board
/Interfaces/I2C1_SDA_HDR: IC1.9 (SDA); also elsewhere on the board
/Interfaces/I/O_HDR2: IC1.2 (GP0); also elsewhere on the board
/Interfaces/I/O_HDR3: IC1.3 (GP1); also elsewhere on the board
/Interfaces/RST_BTN: IC1.4 (~RST); also elsewhere on the board
/USB/CC1: J3.A5 (CC1), R8.1
/USB/CC2: J3.B5 (CC2), R7.1
/USB/GP2: IC1.7 (GP2)
/USB/GP3: IC1.8 (GP3)
/USB/USB_D1+: IC1.12 (D-), U2.3 (I/O2)
/USB/USB_D1-: IC1.13 (D+), U2.1 (I/O1)
/USB/USB_D2+: J3.A6 (D+), J3.B6 (D+), U2.4 (I/O2)
/USB/USB_D2-: J3.A7 (D-), J3.B7 (D-), U2.6 (I/O1)
GND: C3.2, C54.2, IC1.14 (VSS), J3.A1 (GND), J3.A12 (GND), J3.B1 (GND), J3.B12 (GND), R7.2, R8.2, R39.2, U2.2 (GND); also elsewhere on the board
unnamed: C54.1, J3.S1 (SHIELD), R39.1
VBUS_PWR+: J3.A4 (VBUS), J3.A9 (VBUS), J3.B4 (VBUS), J3.B9 (VBUS); also elsewhere on the board

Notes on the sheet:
5V (3A MAX)

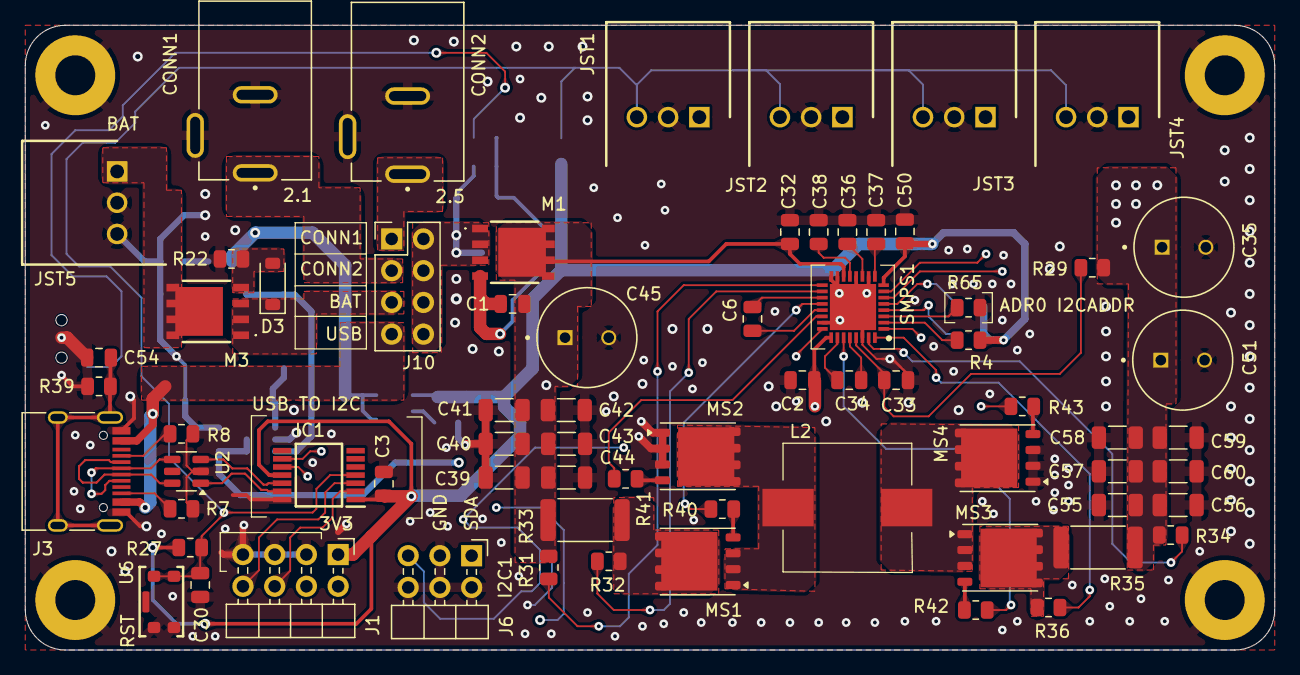
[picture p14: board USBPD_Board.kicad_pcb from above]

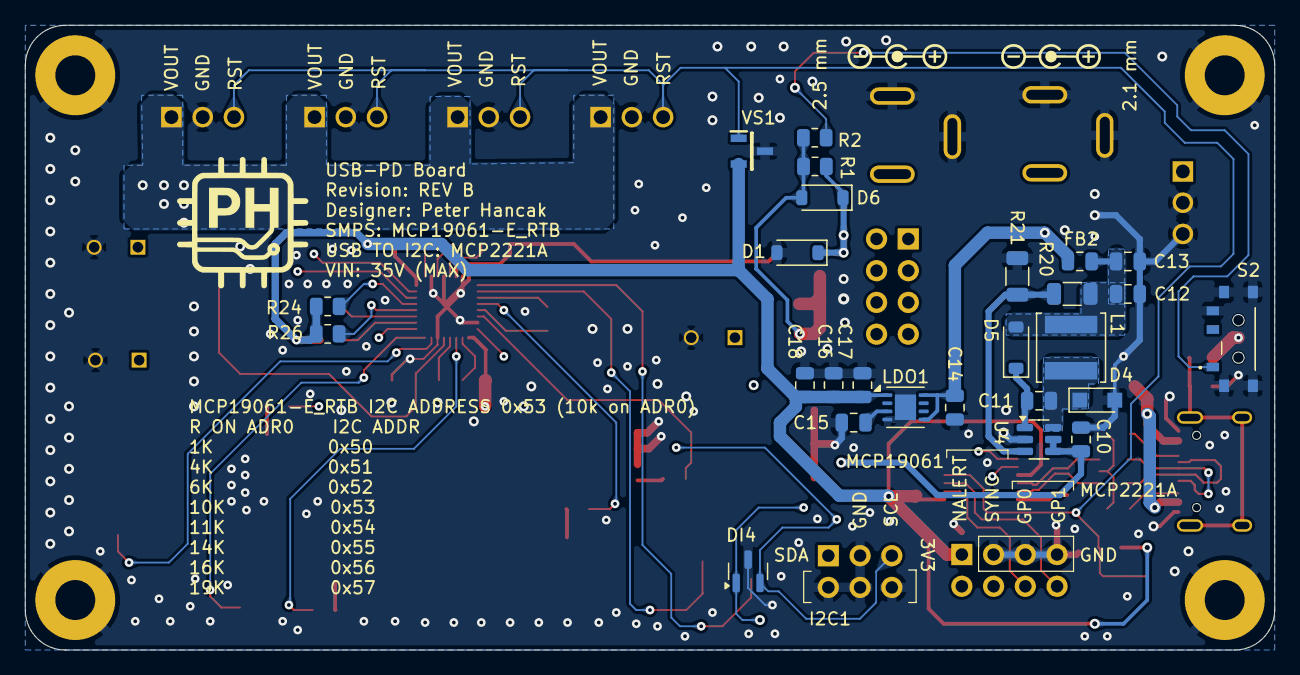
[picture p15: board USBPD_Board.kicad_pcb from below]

Board: 4 copper layers, 100.0 x 50.0 mm, 99 parts (26 on the bottom side), 59 nets.

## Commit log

2026-03-25 Updated the Schematics Doc
    [SMPS_LDO.kicad_sch]
2026-03-25 Updated Schematics PDF Doc
2026-06-24 Change Kicad version
    [Interfaces.kicad_sch, MCP19061.kicad_sch, Power_IO.kicad_sch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]
2026-07-06 Readme Update
    [USBPD_Board.kicad_pcb]
